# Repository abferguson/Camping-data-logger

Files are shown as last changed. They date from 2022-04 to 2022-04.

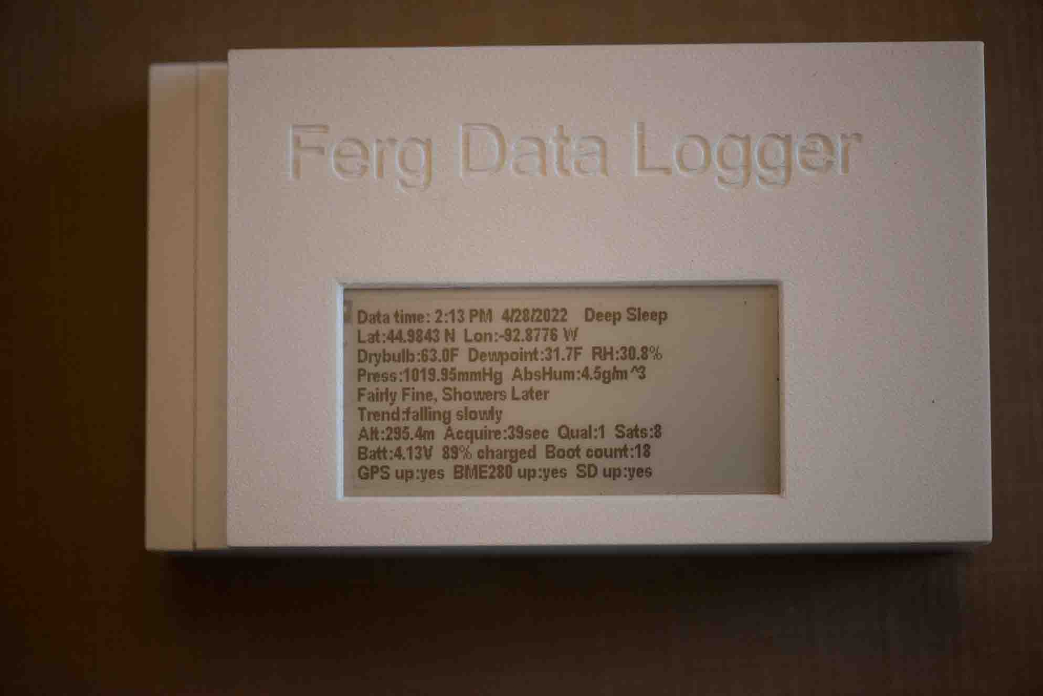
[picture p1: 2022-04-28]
Images/epaper_display.jpg

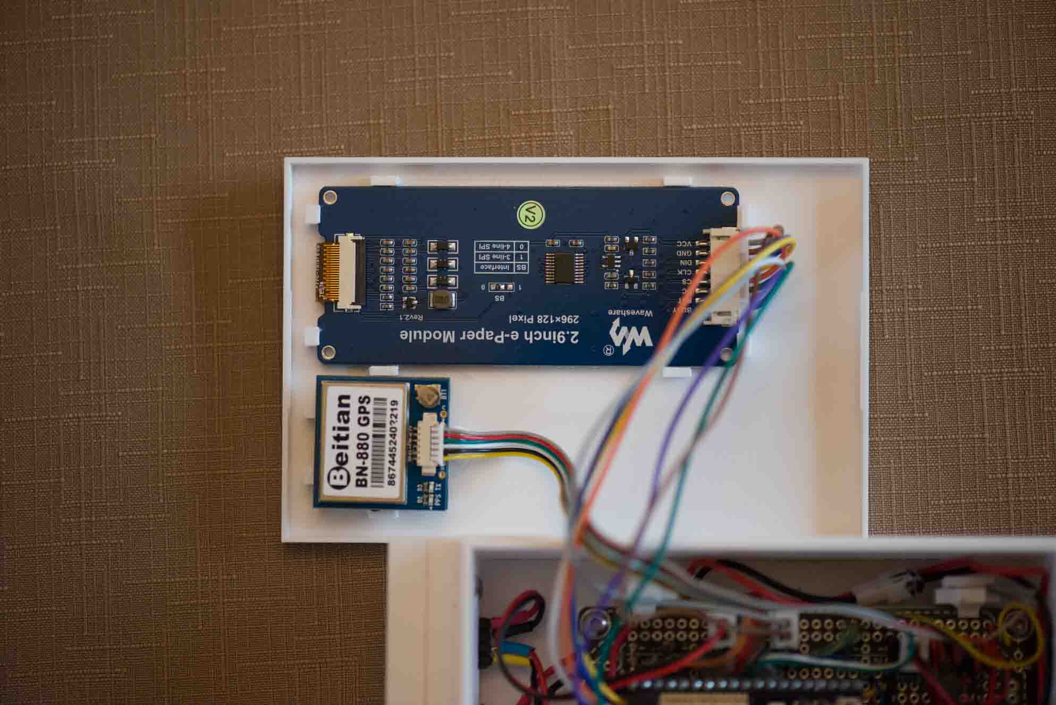
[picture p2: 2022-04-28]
Images/epaper_display_mounting.jpg

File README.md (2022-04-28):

# Camping-data-logger
A battery operated device that stores and allows realtime interaction temperature, humidity, barometric pressure, GPS coordinate and weather prediction data. The Zambretti algorithm for short term weather forecasting is used.  

This repository contains information necessary to build an interactive data logger: CAD files, circuitry and software. Both an OLED and epaper display version are presented here. Any files representing v10 is in reference to the OLED version.

I've made many camping trips into wilderness areas. While an inexpensive plastic thermometer is handy to know the current temperature, more data can be quite helpful. It can be used for selection of clothing as well as post-trip curiosity. This project is my first attempt at creating a data logger for camping.

This device uses the ESP32 mainly for its built-in Bluetooth capability. This feature allows you to use a cell phone to query the data logger (Bluetooth serial) for saved data. The sensors used are the BME280 and BN-880 GPS modules. While powered with a lithium polymer batter, inclusion of the TP4056 provides solar recharging. An onboard OLED or epaper display provides current conditions.

Firmware development: Arduino IDE

Hardware:  
1 x ESP32 MCU + female headers  
1 x BME280 module (I2C) * female header  
1 x BN-880 module (Amazon https://smile.amazon.com/gp/product/B07TY7PL54)    
1 x 132x64 0.96 inch OLED module  (version 10)
1 x 2.9inch e-Paper Display Module, 296x128 (version 11)
1 x Micro SD card module  
1 x LiPo battery (1000 mAh,Amazon https://smile.amazon.com/gp/product/B07TWHH6VF)   
1 x TP4056 battery charge module  
2 x 2N2222 transistor  
2 x MCP1700-3302E linear power regulator  
2 x SPDT slide switch (https://smile.amazon.com/gp/product/B01M1CU2B0)  
1 x power plug adapter (Amazon https://smile.amazon.com/gp/product/B089M7B481) 
various resistors and capacitors  
1 x Circuit Setup protoboard (Amazon https://smile.amazon.com/gp/product/B07HNKJNK3) 
2 x Solar cells (Amazon https://smile.amazon.com/gp/product/B0736W4HK1)  
Several JST connectors  

Circuit schematics: KiCAD format  
One of the linear power regulators provides 3.3v power to the GPS unit. The other powers everything else.  
The transistors are used to switch on power to the SD and GPS units when required. Otherwise, they are off.  

Features:  
- Power switch (inside of main body connects battery to circuitry)  
- Slide switch inside slide cover turns on OLED and places unit in real time display mode  
- Power port for solar cell supply  

Operation:  
-  Once the main power switch is on, the unit begins recording environmental and GPS data every ten minutes.
-  When the interactive slide switch, located behind the sliding cover on the side, is on, two modes are activated:
    1) The unit retrieves the lates environmental data, along with Zambretti forecast and battery voltage level, and displays on the OLED display.
    2) Bluetooth is turned on for interactive queries.  
-  Turn interactive mode off to conserve battery power. The data recording function is disabled when in interactive mode.  
-  The solar cells can be connected at any time.  
  
Bluetooth:  
-  Use a serial bluetooth app to communicate with the data logger.  One app I use is the Serial Bluetooth Terminal by Kai Morich ( Android v1.33 at time of writing)  

-  Once Bluetooth connectivity is established, sending a keyword from a mobile device to the logger will result in the logger returning a data set. This could be current conditions, stored data values, help instructions or miscellaneous data.  
   
Query   --->    Send keyword  
-Environmental --->  env  
-GPS coord --->      gps  
-Current Env --->    now  
-Help --->           help  
-Misc data --->      misc  
-Erase stored data ---> erase  

Notes:  
4 - 3mm x 6mm screws needed to attach side base to case bottom  
2 - 2mm x 5mm screws attach solar cell case bezels to solar cell case frame  
3 - 3mm x 6mm screws to attach battery cage to inside frame  
2 - 2mm x 5mm screws attache SD module to inside frame  
LiPo battery cage is designed for 504040 size  

Assembly:  
- LiPo battery is captured by battery cage, screw fastened  
- TP4056 snops onto inside frame  
- OLED or epaper displays and GPS modules snap onto case top  
- SD module is fastened to inside frame with screws  
- BME280 module soldered to female header (2.54 mm) and plugs into a pin header (male)  

Wiring: 
Using JST 2.0 connectors, I tried to bring I2C and power to each switch, power plug or sensor so that the unit could be more easily assembled/disassembled. 
The battery has its own connector allowing to completly disconnect the battery when not in use. Otherwise, the TP4056 module is still drawing power from the battery even when the system power switch is off.  
The main power switch is on the circuit board along with the discreet resistors, capacitors, transistors and linear power regulators. 
The GPS unit came with its own wiring harness and connector. The wires from the harness are soldered directly to the circuit board.  
The BME280 is soldered to a female pin header. This header fits inside a rectangulare opening allowing a male pin header to connect to it inside the main box.

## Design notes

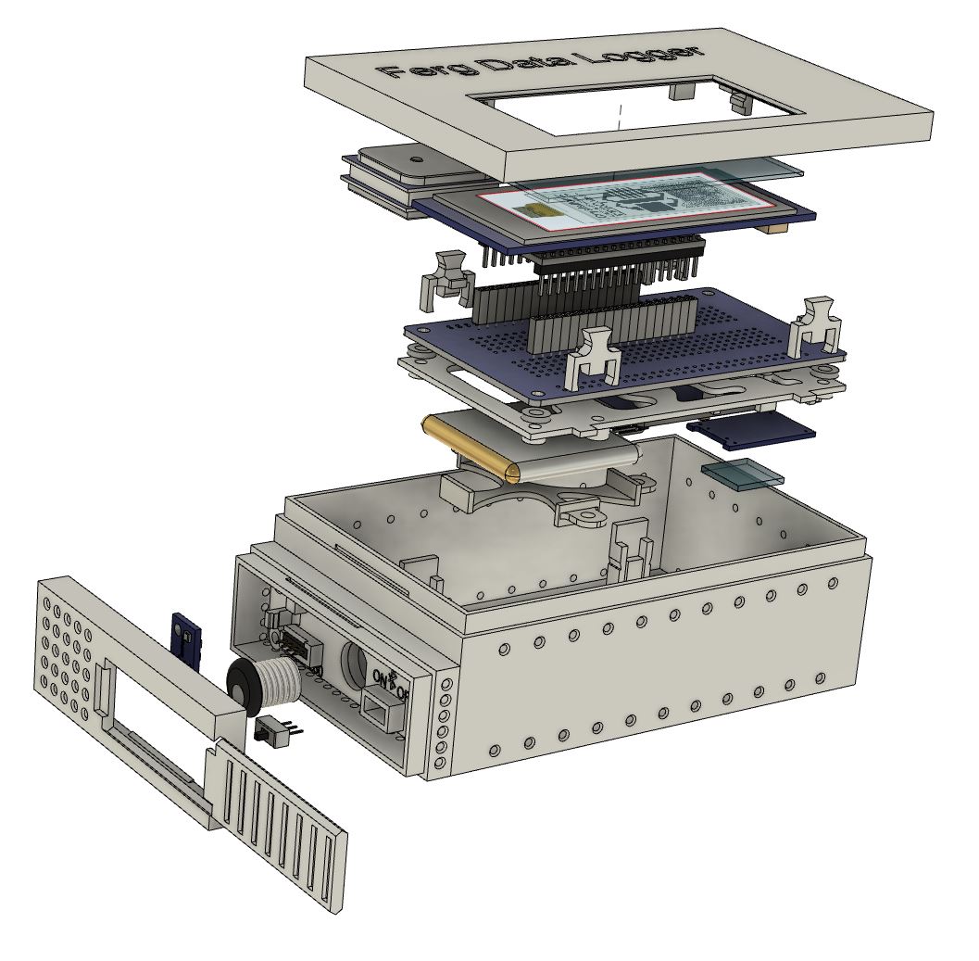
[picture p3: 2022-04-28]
Images/v11_exploded_view.JPG

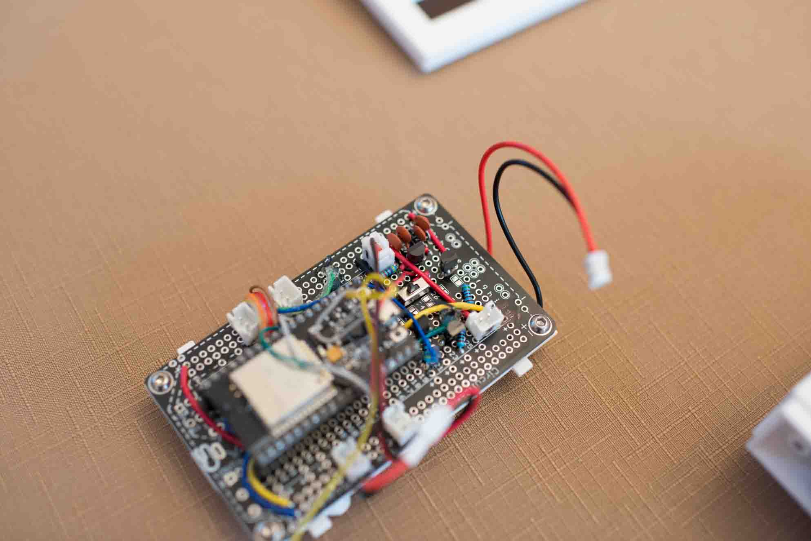
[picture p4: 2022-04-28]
Images/ABF_3100.jpg

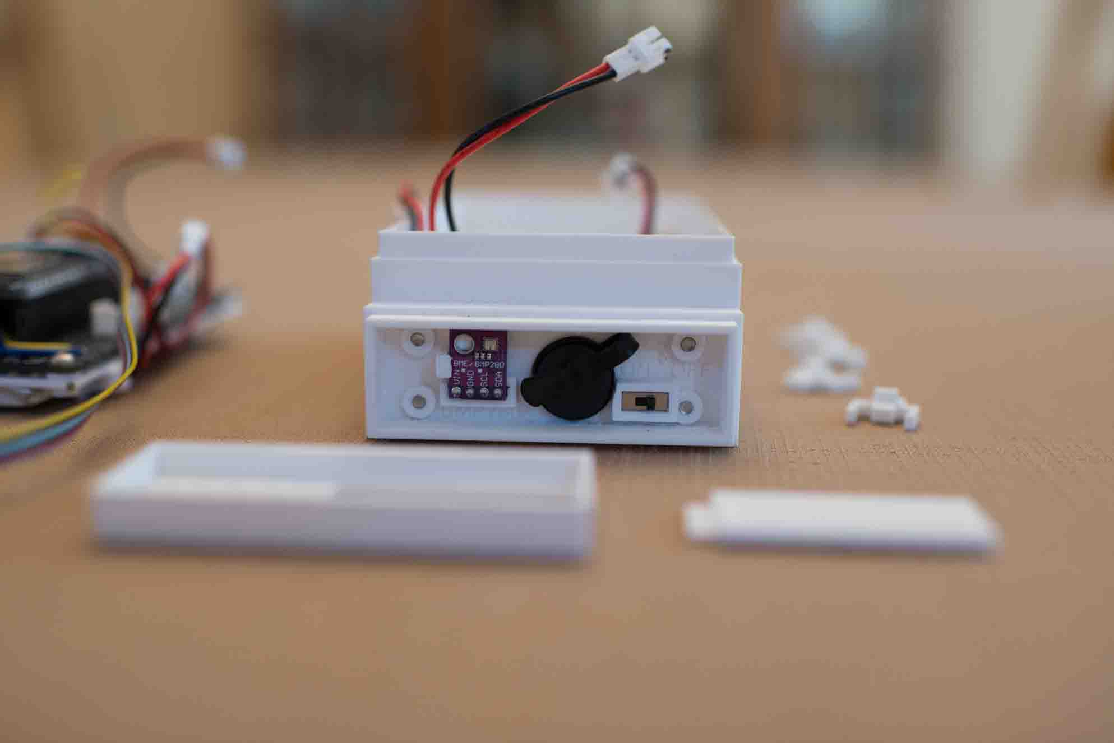
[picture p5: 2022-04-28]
Images/ABF_3093.jpg

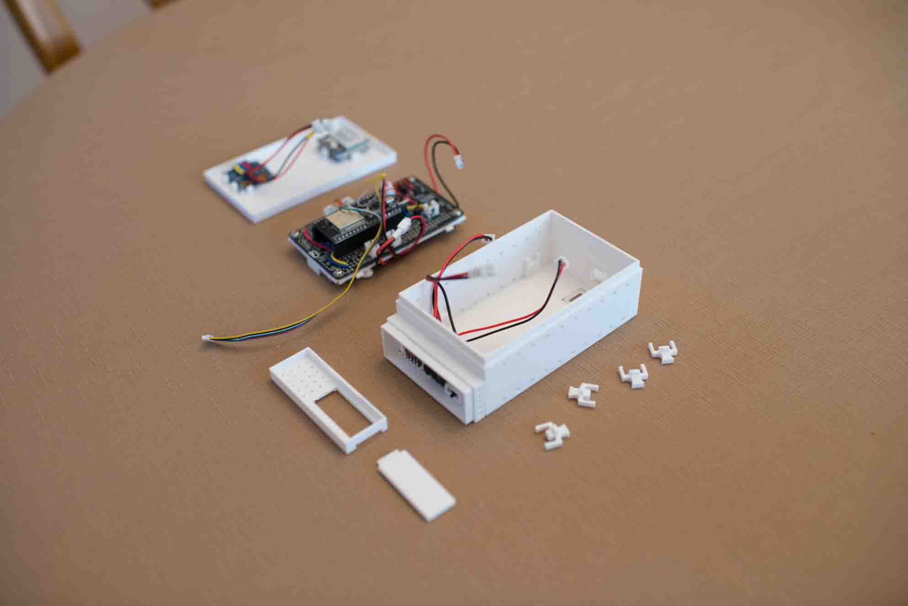
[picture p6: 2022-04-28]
Images/ABF_3094.jpg

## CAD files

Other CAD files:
CAD/504040 Battery Cage v7.f3d
CAD/Breadboard standoffs v3.f3d
CAD/Frame-clip v24.f3d
CAD/Outer Case Bottom v69.f3d
CAD/Outer Case Side Base v59.f3d
CAD/Outer Case Side Cover Slide v7.f3d
CAD/Outer Case Top v33.f3d
CAD/Solar Cell Case Bezel v14.f3d
CAD/Solar Cell Case Frame v34.f3d
CAD/data-logger-inside-frame-504040 v42.f3d
CAD/epaper Outer Case Top.f3d

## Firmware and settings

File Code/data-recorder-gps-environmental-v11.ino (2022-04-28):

/*
   This program periodically logs data from a GPS receiver and a BMP280 environmental sensor and stores
   the data onto a micro SD card.

   MCU: ESP32
   Beitian BN-880 GPS module with magnetic compass capability
   132x64 SSD1306 OLED display module
   BMP280 module
   MicroSD card adaptor (modified to be 3.3 V input instead of 5V)
   TP4056 3.7V Lipo battery charging module
   MCP1500-3302 linear voltage regulator (2)
   2n2222 NPN transistors (2)
   Slide switch (2)
   Power port
   5V solar cell (2)
   
   GPS on Serial2
   Compass (part of GPS) on I2C (not used)
   BME280 on I2C
   OLED on I2C
   SD card reader on SPI

   See KiCAD file 'data_logger v2' for wiring diagram
   
   v1:  General hardware debug with pin/transistor power switching and one RTC hardware wake pin
   v2:  Addition of SPIFFS(ESP32 variety), Zambretti, Arduino Time and Timezone
   v3:  Take out some power pins, work on output format and use boot cause data to choose execution path
   v4:  Add separate pin for sensing bluetooth enable switch
   v5:  Clean up, add data file erase function in bluetooth section, add more data saved and displayed
   v6:  Add smarter gps aquisition (timeout,shorten read time, compare to last saved epoch in SPIFFS)
        Serial output clean up, save cycle time to SD
   v7:  More cleanup. better gps data acquisition handling. rotating screens on oled
        Remove remainder of magnetic compass module code
   v8:  Add bluetooth BLE, fix voltage divider math, 100x average of analog read value
   v9:  Add boot into to datafile and output, estimated time when bad GPS time, boot noted in JSON data
   v10: Add % battery value calculation
   v11: Add ePaper display. Add libraries and code for 2.9 inch ePaper display. Remove OLED display and related code.
*/

#include <Arduino.h>
#include <Wire.h>
#include <Adafruit_GPS.h>
#include <BME280I2C.h>
#include <EnvironmentCalculations.h>
#include <FS.h>
#include <SPI.h>
#include <SD.h>
#include <SPIFFS.h>
#include <TimeLib.h>
#include <Timezone.h>
#include <ArduinoJson.h>
#include "BluetoothSerial.h"
#include <BLEDevice.h>
#include <BLEServer.h>
#include <BLEUtils.h>
#include <BLE2902.h>

int startTime = millis(); // Used to calculate cycle time through program

int swVersion = 11;

 // Central and UTC uints for Timezone library. These need to be defined BEFORE setup().
time_t central;
time_t utc;
TimeChangeRule usCDT = {"CDT", Second, Sun, Mar, 2, -300};  //UTC - 4 hours
TimeChangeRule usCST = {"CST", First, Sun, Nov, 2, -360};   //UTC - 5 hours
Timezone usCentral(usCDT, usCST);

// Used in case GPS does not give a good time stamp during cycle
time_t estTime;

unsigned long current_timestamp;    // Actual timestamp read from NTPtime_t now;
unsigned long saved_timestamp;      // Timestamp stored in SPIFFS

// FORECAST RESULT
int accuracy;                       // Counter, if enough values for accurate forecasting
String ZambrettisWords;             // Final statement about weather forecast
String trend_in_words;              // Trend in words
float pressure_value[12];           // Array for the historical pressure values (6 hours, all 30 mins)
float pressure_difference[12];      // Array to calculate trend with pressure differences

// pin 4 RTC ext0 wakeup
int blueToothPin = 33;
int GPSPowerPin = 13;
int SDPowerPin = 12;
int BattVRead = 36;
int VoltDivPowerPin = 14;
// Serial 2 RX pin = 16;
// Serial 2 TX Pin = 17;

#define GPSSerial Serial2
Adafruit_GPS GPS(&GPSSerial);
uint32_t timer = millis();
uint32_t timer2 = millis();
#define GPSECHO false  // false=turn off GPS data to serial console
bool gpsTimeGood = false;
//int GPSfixQuality = 0;
int GPSwaitTime = 90000;

int uS_TO_S_FACTOR = 1000000;  // Conversion factor for micro seconds to seconds
int TIME_TO_SLEEP = 600;       // Time ESP32 will go to sleep (in seconds)
RTC_DATA_ATTR int bootCount = 0;
RTC_DATA_ATTR int rtcMonth = 0; // Used by Zambretti algorithm
unsigned int savedEpoch = 0;

float tempDewpoint;
float tempDrybulb;
float relHumidity;
float tempHeatindex;
float pressure;
float seaLevelPres;
float absHumidity;
int rel_pressure_rounded;
bool bmefail = false;

float Lati;
float LatiExt;
float Longi;
float LongiExt;
unsigned long acqTime;

float battVoltage = 0;
float percentBattery = 0;

BME280I2C::Settings settings(
   BME280::OSR_X1,
   BME280::OSR_X1,
   BME280::OSR_X1,
   BME280::Mode_Forced,
   BME280::StandbyTime_1000ms,
   BME280::Filter_16,
   BME280::SpiEnable_False,
   BME280I2C::I2CAddr_0x76  //76
);

BME280I2C bme(settings);    // Default : forced mode, standby time = 1000 ms

bool SDfail = false;

File myFile;
File dataFile;

const char TEXT_RISING_FAST[] = "rising quickly";
const char TEXT_RISING[]      = "rising";
const char TEXT_RISING_SLOW[] = "rising slowly";
const char TEXT_STEADY[]      = "steady";
const char TEXT_FALLING_SLOW[]= "falling slowly";
const char TEXT_FALLING[]     = "falling";
const char TEXT_FALLING_FAST[]= "falling quickly";

const char TEXT_ZAMBRETTI_A[] = "Settled, Fine Weather";
const char TEXT_ZAMBRETTI_B[] = "Fine Weather";
const char TEXT_ZAMBRETTI_C[] = "Becoming Fine";
const char TEXT_ZAMBRETTI_D[] = "Fine, Becoming Less Settled";
const char TEXT_ZAMBRETTI_E[] = "Fine, Possibly showers";
const char TEXT_ZAMBRETTI_F[] = "Fairly Fine, Improving";
const char TEXT_ZAMBRETTI_G[] = "Fairly Fine, Possibly showers early";
const char TEXT_ZAMBRETTI_H[] = "Fairly Fine, Showers Later";
const char TEXT_ZAMBRETTI_I[] = "Showery Early, Improving";
const char TEXT_ZAMBRETTI_J[] = "Changeable, Improving";
const char TEXT_ZAMBRETTI_K[] = "Fairly Fine, Showers likely";
const char TEXT_ZAMBRETTI_L[] = "Rather Unsettled, Clearing Later";
const char TEXT_ZAMBRETTI_M[] = "Unsettled, Probably Improving";
const char TEXT_ZAMBRETTI_N[] = "Showery Bright Intervals";
const char TEXT_ZAMBRETTI_O[] = "Showery Becoming Unsettled";
const char TEXT_ZAMBRETTI_P[] = "Changeable, some rain";
const char TEXT_ZAMBRETTI_Q[] = "Unsettled, short fine Intervals";
const char TEXT_ZAMBRETTI_R[] = "Unsettled, Rain later";
const char TEXT_ZAMBRETTI_S[] = "Unsettled, rain at times";
const char TEXT_ZAMBRETTI_T[] = "Very Unsettled, Finer at times";
const char TEXT_ZAMBRETTI_U[] = "Rain at times, Worse later";
const char TEXT_ZAMBRETTI_V[] = "Rain at times, becoming very unsettled";
const char TEXT_ZAMBRETTI_W[] = "Rain at Frequent Intervals";
const char TEXT_ZAMBRETTI_X[] = "Very Unsettled, Rain";
const char TEXT_ZAMBRETTI_Y[] = "Stormy, possibly improving";
const char TEXT_ZAMBRETTI_Z[] = "Stormy, much rain";
const char TEXT_ZAMBRETTI_DEFAULT[] = "Sorry, no forecast for the moment";

BluetoothSerial SerialBT;
String Stdbtmessage = "";
bool newStdbtmessage = false;
const size_t capacity = JSON_OBJECT_SIZE(30) + 500;
DynamicJsonDocument jsondata(capacity);

BLECharacteristic *pCharacteristic;
#define SERVICE_UUID           "6E400001-B5A3-F393-E0A9-E50E24DCCA9E" // UART service UUID
#define CHARACTERISTIC_UUID_RX "6E400002-B5A3-F393-E0A9-E50E24DCCA9E"
#define CHARACTERISTIC_UUID_TX "6E400003-B5A3-F393-E0A9-E50E24DCCA9E"
bool deviceConnected = false;
String BLEmessage = "";
bool newBLEmessage = false;

boolean mounted = false;

// 2.9 in epaper display stuff
#include <GxEPD2_BW.h> // 2.9 in epaper display
#include <Fonts/arialnb8pt7b.h> // 2.9 in epaper display
#include <Fonts/arialnb7pt7b.h> // 2.9 in epaper display

#define ENABLE_GxEPD2_GFX 0

#define GxEPD2_DISPLAY_CLASS GxEPD2_BW
#define GxEPD2_DRIVER_CLASS GxEPD2_290_T94 // GDEM029T94  128x296, SSD1680
#define GxEPD2_BW_IS_GxEPD2_BW true
#define IS_GxEPD2_BW(x) IS_GxEPD(GxEPD2_BW_IS_, x)
#define GxEPD2_290_T94_IS_BW true
#define IS_GxEPD2_DRIVER_BW(x) IS_GxEPD2_DRIVER(x, _IS_BW)
#if defined(ESP32)
  #define MAX_DISPLAY_BUFFER_SIZE 65536ul // e.g.
  #define MAX_HEIGHT(EPD) (EPD::HEIGHT <= MAX_DISPLAY_BUFFER_SIZE / (EPD::WIDTH / 8) ? EPD::HEIGHT : MAX_DISPLAY_BUFFER_SIZE / (EPD::WIDTH / 8))
  GxEPD2_DISPLAY_CLASS<GxEPD2_DRIVER_CLASS, MAX_HEIGHT(GxEPD2_DRIVER_CLASS)> epdDisplay(GxEPD2_DRIVER_CLASS(/*CS=*/ 14, /*DC=*/ 25, /*RST=*/ 15, /*BUSY=*/ 26));
#endif


class MyServerCallbacks: public BLEServerCallbacks {
    void onConnect(BLEServer* pServer) {
      deviceConnected = true;
//      Serial.println("BLE connected");
    };

    void onDisconnect(BLEServer* pServer) {
      deviceConnected = false;
//      Serial.println("BLE disconnected");
    }
};

class MyCallbacks: public BLECharacteristicCallbacks {
  void onWrite(BLECharacteristic *pCharacteristic) {
    std::string rxValue = pCharacteristic->getValue();

    if (rxValue.length() > 0) {
//      Serial.print("Received new BLErxValue: ");

      String tempBLErxValue;
      for (int i = 0; i < rxValue.length();) {
        tempBLErxValue += rxValue[i];
        if(tempBLErxValue == "env" || tempBLErxValue == "gps" || tempBLErxValue == "now" || tempBLErxValue == "help" || tempBLErxValue == "misc" || tempBLErxValue == "erase") {
          BLEmessage = tempBLErxValue; // ignore any LF or CR  
        }
        i++;
      } // for
      BLEmessage += "BLE";
      Serial.println(BLEmessage);
      newBLEmessage = true;
    } // if
  } // void onWrite
}; // class MyCallbacks:

//--------------------------------------------------------------------
void setup() {
//  WiFi.disconnect(true);
//  WiFi.mode(WIFI_OFF);
  btStop();
  
  pinMode(BattVRead, INPUT);
  pinMode(GPSPowerPin, OUTPUT);
  pinMode(SDPowerPin, OUTPUT);
  pinMode(VoltDivPowerPin, OUTPUT);
  pinMode(blueToothPin, INPUT_PULLDOWN); // Defining this as pin4 input causes issues with the wakeup working correctly
  
  digitalWrite(VoltDivPowerPin, HIGH); // Connect GND (GPS and voltage divider)
  digitalWrite(SDPowerPin, HIGH); // Switch power on to GPS module
  delay(20);
  
  Wire.begin();
  Wire.setClock(400000);  // Speed up i2c wire speed. This works
  
  epdDisplay.init(115200); // Start epaper display
  
  Serial.begin(115200);
  while(!Serial) // Wait for Serial to become available
    ;
//  Serial.print("");
//  Serial.println("--------------------------------------------------------");


  ++bootCount;
//  Serial.print("Firmware version: ");
//  Serial.println(swVersion);
//  Serial.println("Boot number: " + String(bootCount));
//  Serial.println("rtcMonth: " + String(rtcMonth));

  printWakeupReason();
  
  mounted = SPIFFS.begin(); // Turn on SPIFFS before bluetooth or regular section

  esp_sleep_enable_timer_wakeup(TIME_TO_SLEEP * uS_TO_S_FACTOR); // Enable wake up when a set time has past
//  Serial.println("Setup: ESP32 to sleep for every " + String(TIME_TO_SLEEP) + " Seconds");
  esp_sleep_enable_ext0_wakeup(GPIO_NUM_4,1); //1 = High, 0 = Low // Enable wake up when pin 4 goes high


  esp_sleep_wakeup_cause_t wakeup_reason;
  wakeup_reason = esp_sleep_get_wakeup_cause();
  switch(wakeup_reason) {
    case ESP_SLEEP_WAKEUP_EXT0: 
      if (!SD.begin()) {
//        Serial.println("SD module initialization failed!");
        return;
      }
//      Serial.println("######### external wake #########");


      SerialBT.begin(" Std Datalogger"); // Bluetooth device name
//      Serial.println("Ready for Standard Bluetooth");

 
      // Create the BLE Device
      BLEDevice::init(" BLE Datalogger"); // Give it a name

      // Create the BLE Server
      BLEServer *pServer = BLEDevice::createServer();
      pServer->setCallbacks(new MyServerCallbacks());

      // Create the BLE Service
      BLEService *pService = pServer->createService(SERVICE_UUID);

      // Create a BLE Characteristic
      pCharacteristic = pService->createCharacteristic(
        CHARACTERISTIC_UUID_TX,
        BLECharacteristic::PROPERTY_NOTIFY
      );
                      
      pCharacteristic->addDescriptor(new BLE2902());

      BLECharacteristic *pCharacteristic = pService->createCharacteristic(
        CHARACTERISTIC_UUID_RX,
        BLECharacteristic::PROPERTY_WRITE
      );

      pCharacteristic->setCallbacks(new MyCallbacks());

      // Start the service
      pService->start();

      // Start advertising
      pServer->getAdvertising()->start();
//      Serial.println("Ready for Bluetooth BLE");

     
      blueTooth();
      
      btStop();
      SerialBT.flush();
      SerialBT.disconnect();
      SerialBT.end();
    break;

  } // switch

  GPSupdatingMsgEPD(); // Send wake reason and GPS startup messages to display

// Turn on GPS module after bluetooth section
  digitalWrite(GPSPowerPin, HIGH); // Switch on ground connection to GPS module
  delay(500); // let power settle

  
//  Serial.println();
  checkSPIFFS();

// Read battery voltage
  readBattVoltage();
  
// GPS
  readSavedEpoch();
//  Serial.print("savedEpoch: ");
//  Serial.println(savedEpoch);
  readGPS();
  GPS.standby();

// Timezone adjustment
  // set the Time to the latest GPS reading
//  Serial.println();
//  Serial.println("Date and time...");
  timezoneAdjust();

// BME280
  BME280Read();
  
// Zambretti depends on GPS time and BME pressure
  Spiffs_Zambretti_update();
  
// SD card write
  saveDataToSD();
  
// Saves local time to SD
  writeSavedEpoch();

// Update epaper display with current values
  updateEPD();
  
  digitalWrite(SDPowerPin, LOW); // Switch power off to SD module
  digitalWrite(GPSPowerPin, LOW); // Switch power off to GPS module
  digitalWrite(VoltDivPowerPin, LOW); // Disconnect GND to buck converter (power for GPS, voltage divider)
  
//  Serial.println();
//  Serial.println("end of setup()");
//  Serial.println();
//  Serial.println("Setup: ESP32 going to sleep for every " + String(TIME_TO_SLEEP) + " Seconds");

  Serial.println();
  Serial.print("Elapsed time through setup(): ");
  Serial.println(millis() - startTime);
  Serial.flush(); 

  esp_deep_sleep_start();
} // setup

//==================================================
void loop() {
} // loop()
//==================================================


void GPSupdatingMsgEPD() {
  Serial.println("In GPSupdatingMsgEPF()");
  int16_t tbx;
  int16_t tby;
  uint16_t tbw;
  uint16_t tbh;

  // Vertical pixel spacing between lines of ePaper display
  int spacer = 2;

  String startupMode = "Acquiring GPS fix";
  epdDisplay.setRotation(3);
  epdDisplay.setFont(&arialnb8pt7b);
  epdDisplay.getTextBounds(startupMode, 0, 0, &tbx, &tby, &tbw, &tbh);
  epdDisplay.setTextColor(GxEPD_BLACK);
  epdDisplay.setFullWindow();
  epdDisplay.firstPage();
  do {
    epdDisplay.fillScreen(GxEPD_WHITE);
    epdDisplay.setCursor(0, tbh);
    epdDisplay.print(startupMode);
  }
  while (epdDisplay.nextPage());

  Serial.println("finish GPSupdatingMsgEPD()");
}  // GPSupdatingMsgEPD()

void updateEPD() {
  Serial.println("updateEPD()...");
  epdDisplay.setRotation(3);
  epdDisplay.setFont(&arialnb7pt7b);
  epdDisplay.setTextColor(GxEPD_BLACK);

  if(gpsTimeGood) { // If valid GPS data not aqcuired in time
    Lati = (float)GPS.latitude_fixed/10000000.0;
    Longi = (float)GPS.longitude_fixed/10000000.0;
  }
  else {
    Lati = 0;
    LatiExt = char('-');
    Longi = 0;
    LongiExt = char('-');
  }
  
  // Vertical pixel spacing between lines of ePaper display
  int spacer = 1;
  
  hourFormat12(); // Change to 12 hour format
  String amPM;
  if(isAM()) {
    amPM = "AM";
  }
  else {
    amPM = "PM";
  }

  String GPSstatus;
  if(gpsTimeGood) {
    GPSstatus = "yes";
  }
  else {
    GPSstatus = "no";
  }

  String BMEstatus;
  if(!bmefail) {
    BMEstatus = "yes";
  }
  else {
    BMEstatus = "no";
  }

  String SDstatus;
  if(!SDfail) {
    SDstatus = "yes";
  }
  else {
    SDstatus = "no";
  }
  
  int16_t tbx;
  int16_t tby;
  uint16_t tbw;
  uint16_t tbh;

  String hourMod = String(hour());
  if(hour() > 12) {
    hourMod = String(hour() - 12);
  }
  
  String minuteZero = "";
  if(minute() < 10) {
    minuteZero = "0";  
  }
  
  String timeText = "Data time: " + hourMod + ":" + minuteZero + String(minute()) + " " + amPM + "  " + month() + "/" + day() + "/" + year() + "    Deep Sleep";
  String latlongText = "Lat:" + String(Lati,4) + " " + GPS.lat + "  Lon:" + String(Longi,4) + " " + GPS.lon;
  String weatherText = "Drybulb:" + String(tempDrybulb,1) + "F  Dewpoint:" + String(tempDewpoint,1) + "F  RH:" + String(relHumidity,1) + "%";
  String weatherText2 = "Press:" + String(seaLevelPres) + "mmHg  AbsHum:" + String(absHumidity,1) + "g/m^3";
  String trending = "Trend:" + trend_in_words;
  String gpsStats = "Alt:" + String(GPS.altitude,1) + "m  Acquire:" + acqTime + "sec  Qual:" + String(GPS.fixquality) + "  Sats:" + String(GPS.satellites);
  String battStats = "Batt:" + String(battVoltage) + "V  " + String(percentBattery,0) + "% charged  Boot count:" + String(bootCount);
  String errorMsgs = "GPS up:" + GPSstatus + "  BME280 up:" + BMEstatus + "  SD up:" + SDstatus;
  
  epdDisplay.getTextBounds(timeText, 0, 0, &tbx, &tby, &tbw, &tbh);
  // Center bounding box by transposition of origin:
  epdDisplay.setFullWindow();
  epdDisplay.firstPage();
  do {
    epdDisplay.fillScreen(GxEPD_WHITE);
    epdDisplay.setCursor(0, tbh);
    epdDisplay.print(timeText);

    epdDisplay.setCursor(0,(2*(tbh+spacer)-spacer));
    epdDisplay.print(latlongText);

    epdDisplay.setCursor(0,(3*(tbh+spacer)-spacer));
    epdDisplay.print(weatherText);

    epdDisplay.setCursor(0,(4*(tbh+spacer)-spacer));
    epdDisplay.print(weatherText2);

    epdDisplay.setCursor(0,(5*(tbh+spacer)-spacer));
    epdDisplay.print(ZambrettisWords);

    epdDisplay.setCursor(0,(6*(tbh+spacer)-spacer));
    epdDisplay.print(trending);

    epdDisplay.setCursor(0,(7*(tbh+spacer)-spacer));
    epdDisplay.print(gpsStats);

    epdDisplay.setCursor(0,(8*(tbh+spacer)-spacer));
    epdDisplay.print(battStats);

    epdDisplay.setCursor(0,(9*(tbh+spacer)-spacer));
    epdDisplay.print(errorMsgs);

    
  }
  while (epdDisplay.nextPage());

  Serial.println("finish updateEPD()");
} // void updateEPD()

void epdDisplayWhite() {
// This is only called when switch inside side compartment is on
// When powering down, switch side switch on first, then turn off switch inside main case
  epdDisplay.setFullWindow();
  epdDisplay.firstPage();
  epdDisplay.fillScreen(GxEPD_WHITE);
  while (epdDisplay.nextPage());
  epdDisplay.powerOff();
} // epdDisplayWhite()

void blueTooth() {
  bool blueToothMode = true;

  epdDisplayWhite(); // Turn epaper display all white
  
  while(blueToothMode) { // Exit when bluetooth switch goes off

// This section can be used for ouputting bme280 data to screen
// Originally used for oled screen    
   
    if(SerialBT.available()) { // Assemble String btmessage from standard bluetooth input
      char incomingChar = SerialBT.read();
      if (incomingChar != '\n'){
        Stdbtmessage += String(incomingChar);
      }
      else{
        Stdbtmessage = "";
      }
      Serial.write(incomingChar);  
    } // BT.available
  
  // Check SD related btmessage and control output accordingly
    if(Stdbtmessage == "env" || Stdbtmessage == "gps" || Stdbtmessage == "now"  || Stdbtmessage == "help" || Stdbtmessage == "misc" || Stdbtmessage == "erase"){
      Stdbtmessage += "STD"; // Add STD to message to delineate
      newStdbtmessage = true;
//      Serial.println("calling bluetoothReply()");
      bluetoothReply(Stdbtmessage);
//      Serial.println("returned from bluetoothReply()");
      newStdbtmessage = false;
      Stdbtmessage = "";
    }

    if(deviceConnected && newBLEmessage) {
//      Serial.println("calling bluetoothReply()");
      bluetoothReply(BLEmessage);
//      Serial.println("returned from bluetoothReply()");
      newBLEmessage = false;
      BLEmessage = "";
    }

    blueToothMode = digitalRead(blueToothPin); // Read blueToothPin
  } // while blueToothMode
} // blueTooth()

void checkSPIFFS() {
//  Serial.println("SPIFFS FS check...");
  if (!mounted) {
//    Serial.println("  FS not formatted. Doing that now... (can last up to 30 sec).");
    SPIFFS.format();
//    Serial.println("  FS formatted...");
    SPIFFS.begin();
  }
  else {
//    Serial.println("  SPIFFS FS is already formatted.");
  }
//  Serial.println("finish SPIFFS FS check"); 
} // void checkSPIFFS()

void bluetoothReply(String btmessage) {
  String replyStr = "";
  if(btmessage == "nowSTD" || btmessage == "nowBLE") {
    BME280Read();
    readBattVoltage();
    ReadFromSPIFFS();
    ZambrettisWords = ZambrettiSays(char(ZambrettiLetter()));
  
    replyStr = "Temperature: " + String(tempDrybulb,1) + " F\n";
    replyStr += "%Rel Humidity: " + String(relHumidity,1) + "\n";
    replyStr += "Dewpoint: " + String(tempDewpoint,1) + " F\n";
    replyStr += "Pressure: " + String(seaLevelPres,1) + " hPa\n";
    replyStr += "Absolute Humidity: " + String(absHumidity,1) + " g/m^3\n";
    replyStr += "Zambretti: " + ZambrettisWords + "\n";
    replyStr += "Trend: " + trend_in_words + "\n";
    replyStr += "Battery voltage: " + String(battVoltage,1) + " V\n\n";
    sendToBluetooth(replyStr);
  } // if now call

//  Serial.println("Opening file for read only");
  myFile = SD.open("/data.txt", FILE_READ);

// For values that are time related only...  
  if (myFile && (btmessage == "envSTD" || btmessage == "envBLE" || btmessage == "gpsSTD" || btmessage == "gpsBLE" || btmessage == "miscSTD" || btmessage == "miscBLE")) {
    String inputString = "";
    while (myFile.available()) {
      inputString = myFile.readStringUntil('\n');
      deserializeJson(jsondata,inputString); // convert String to JSON
//      serializeJson(jsondata,Serial); // print JSON to serial

      int bootcnt = jsondata["bootcnt"];
      if(bootcnt == 1) {
        replyStr += "\nBoot\n";
      }
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

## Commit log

2020-11-09 Create Circuit
2022-04-28 Assembled and exploded views for v11 (epaper display)
2022-04-28 Outer top CAD for epaper display
    [epaper Outer Case Top.f3d]
2022-04-28 epaper circuit files addes
    [epaper_data_logger.sch]
2022-04-28 schematic for OLED version
    [data_logger.sch]
